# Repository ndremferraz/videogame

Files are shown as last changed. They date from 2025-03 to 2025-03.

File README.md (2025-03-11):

# Video Game Project (Finished🏁)
The purpose of this repository is to document my process of creating a handheld video game console. My intention with this project is to practice some skills realted to embedded software and electronics while I do something fun.

The Project used a Raspberry Pi Pico to connect to control a OLED screen equiped with a SSD1306 chip using I2C protocol, inputs were read from the a Joystick and 4 different buttons.

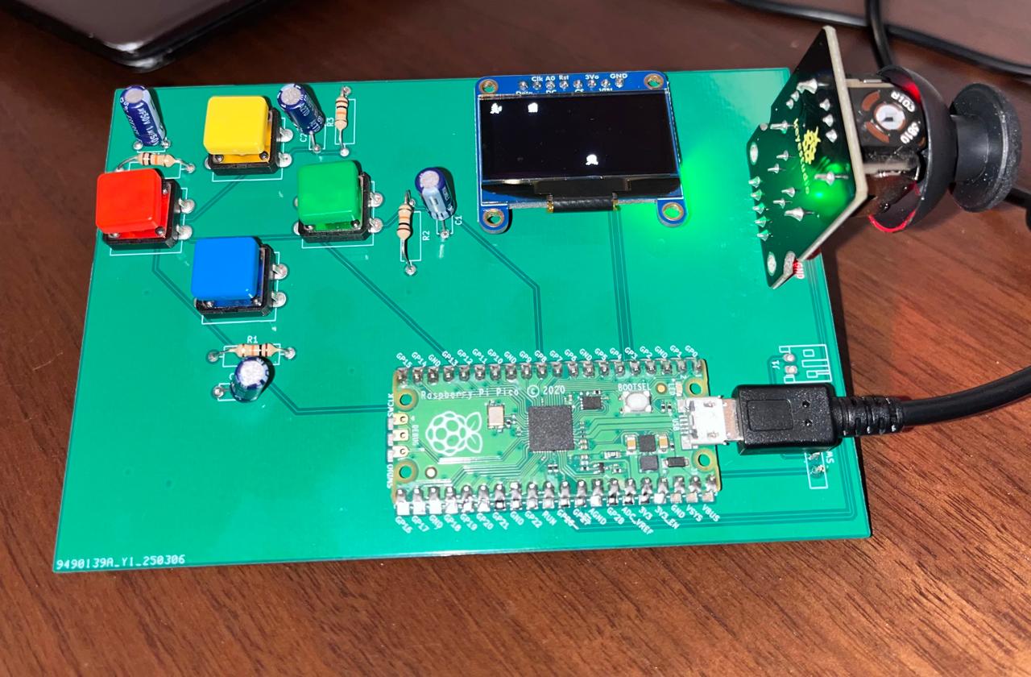
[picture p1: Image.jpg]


In this Project I not only wrote the code using the C/C++ SDK but also designed a PCB for the Circuit. 

The Code can be found under the videogame subfolder and Schematics and PCB found under PacmanProject(Which was the original Idea)

For the creating of the ssd1306.c file I did base myself on the ssd1306 example provided by the raspberry pi foundation, the rest is all mine.

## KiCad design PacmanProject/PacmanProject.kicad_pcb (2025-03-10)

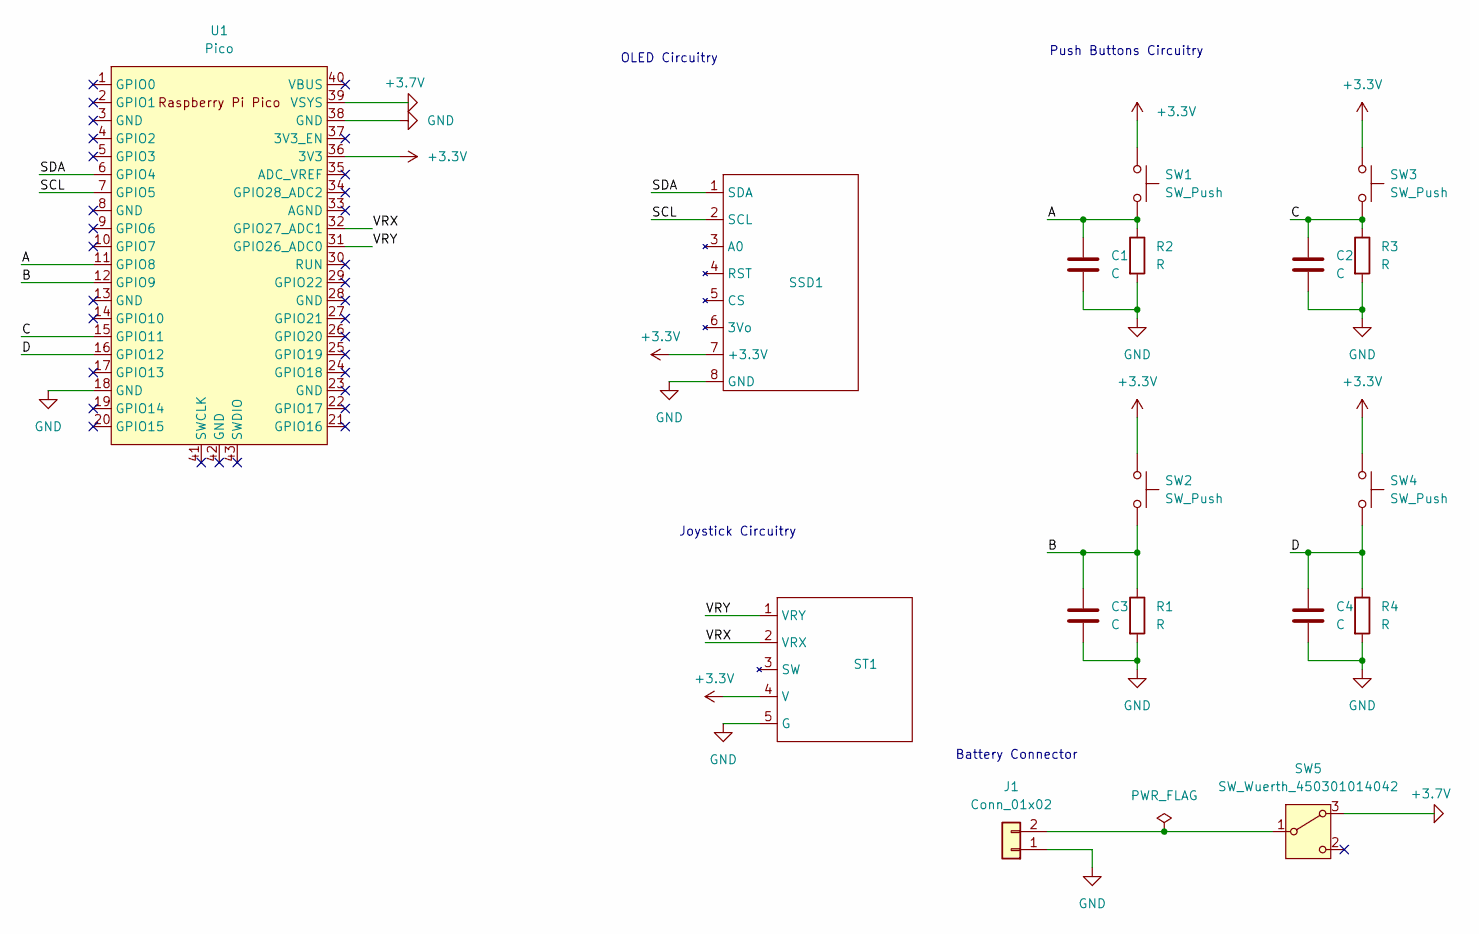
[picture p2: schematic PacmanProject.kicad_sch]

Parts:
C1, C2, C3, C4: C; C_Disc_D4.7mm_W2.5mm_P5.00mm
J1: Conn_01x02; JST_PH_S2B-PH-K_1x02_P2.00mm_Horizontal
R1, R2, R3, R4: R; R_Axial_DIN0309_L9.0mm_D3.2mm_P12.70mm_Horizontal
SSD1: Screen
ST1: joystickV2
SW1, SW2, SW3, SW4: SW_Push; SW_PUSH-12mm_Wuerth-430476085716
SW5: SW_Wuerth_450301014042; SW_Slide-03_Wuerth-WS-SLTV_10x2.5x6.4_P2.54mm
U1: Pico; RPi_Pico_SMD_TH

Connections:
+3.3V: SSD1.7 (+3.3V), ST1.4 (V), SW1.1, SW2.1, SW3.1, SW4.1, U1.36 (3V3)
+3.7V: SW5.3 (A), U1.39 (VSYS)
/A: C1.1, R2.1, SW1.2, U1.11 (GPIO8)
/B: C3.1, R1.1, SW2.2, U1.12 (GPIO9)
/C: C2.1, R3.1, SW3.2, U1.15 (GPIO11)
/D: C4.1, R4.1, SW4.2, U1.16 (GPIO12)
/SCL: SSD1.2 (SCL), U1.7 (GPIO5)
/SDA: SSD1.1 (SDA), U1.6 (GPIO4)
/VRX: ST1.2 (VRX), U1.32 (GPIO27_ADC1)
/VRY: ST1.1 (VRY), U1.31 (GPIO26_ADC0)
GND: C1.2, C2.2, C3.2, C4.2, J1.1, R1.2, R2.2, R3.2, R4.2, SSD1.8 (GND), ST1.5 (G), U1.18 (GND), U1.38 (GND)
unnamed: J1.2, SW5.1 (B)

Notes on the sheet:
Push Buttons Circuitry
Joystick Circuitry
OLED Circuitry
Battery Connector

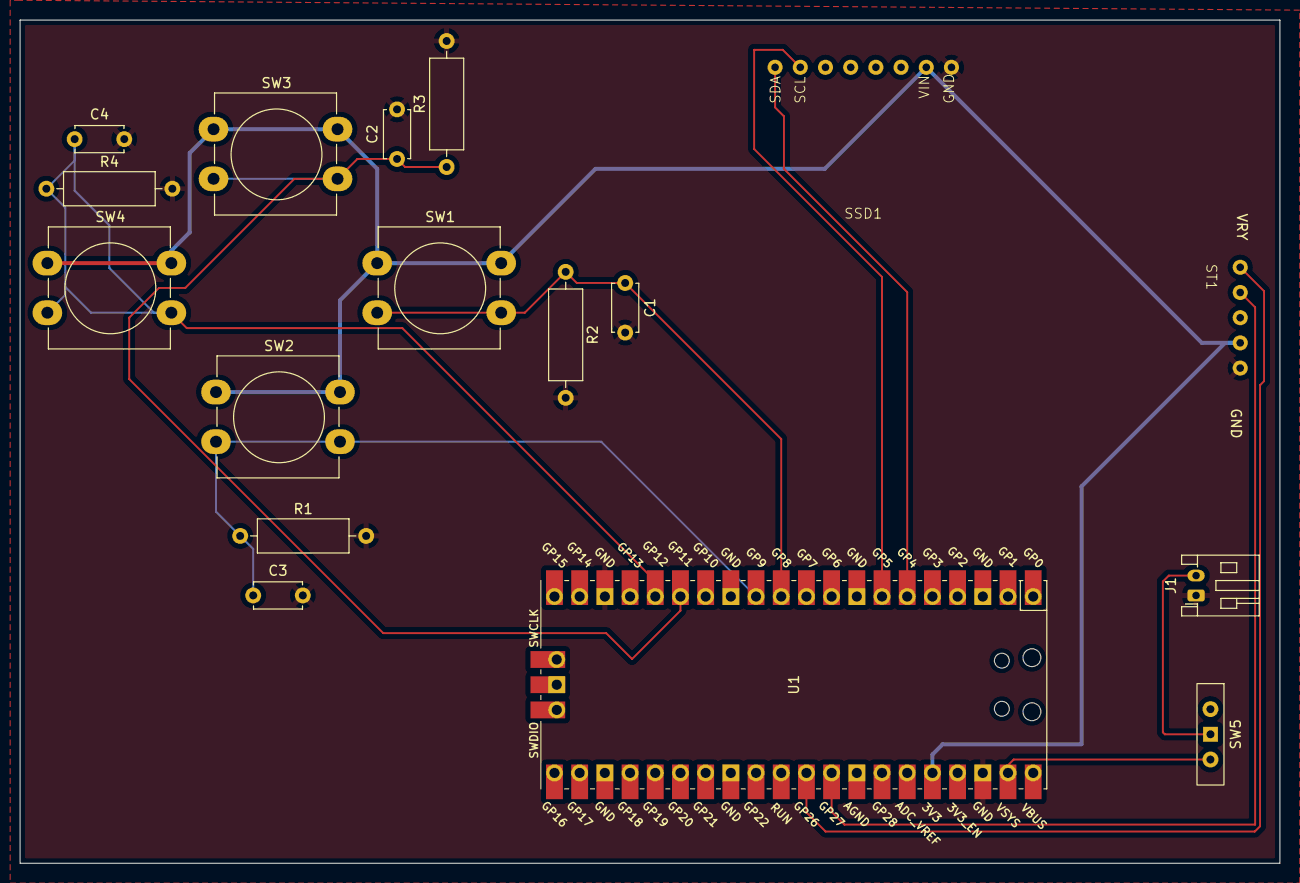
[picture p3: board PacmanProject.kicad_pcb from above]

Board: 2 copper layers, 127.0 x 85.0 mm, 17 parts (0 on the bottom side), 12 nets.

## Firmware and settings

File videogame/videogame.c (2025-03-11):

#include <stdio.h>
#include "pico/rand.h"
#include "pico/stdlib.h"
#include "pico/binary_info.h"
#include "hardware/gpio.h"
#include "hardware/adc.h"
#include "hardware/i2c.h"
#include "ssd1306.h"
#include "character_images.h"
#include "game.h"

//pins 10 and 13 are likely burned :)
//Definitions for the buttons and joystick
#define GREENBUTTON 11
#define YELLOWBUTTON 8
#define REDBUTTON 12
#define BLUEBUTTON 9

#define XJOYSTICK 27
#define YJOYSTICK 26

//Initializing the I/O pins
void init_gpios(){
    gpio_init(GREENBUTTON);
    gpio_init(YELLOWBUTTON);
    gpio_init(REDBUTTON);
    gpio_init(BLUEBUTTON);
    

    gpio_set_dir(GREENBUTTON, GPIO_IN);
    gpio_set_dir(YELLOWBUTTON, GPIO_IN);
    gpio_set_dir(REDBUTTON, GPIO_IN);
    gpio_set_dir(BLUEBUTTON, GPIO_IN);
}

//initializing i2c using the default i2c in the pico
//DATA > GPIO4 
//CLK > GPIO5
void i2c_setup(){

    i2c_init(i2c_default, 100 * 1000);
    gpio_set_function(PICO_DEFAULT_I2C_SDA_PIN, GPIO_FUNC_I2C);
    gpio_set_function(PICO_DEFAULT_I2C_SCL_PIN, GPIO_FUNC_I2C);
    gpio_pull_up(PICO_DEFAULT_I2C_SDA_PIN);
    gpio_pull_up(PICO_DEFAULT_I2C_SCL_PIN);

    bi_decl(bi_2pins_with_func(PICO_DEFAULT_I2C_SDA_PIN, PICO_DEFAULT_I2C_SCL_PIN, GPIO_FUNC_I2C));
}


//function finds the index of bytes of each character 
//each character has a width of 8 bytes stacked vertically 
//we want one byte adjacent down 
//adjacent bytes are to compensate for misallignment   
void bytes_of_characters(struct player *character, uint16_t *byte_list){

    for(uint8_t i = 0; i < 8; i++){
        byte_list[i] = character->x_pos + i + (character->y_pos / 8)* SSD1306_WIDTH; //index of top byte
        byte_list[i+8] = character->x_pos + i + ((character->y_pos / 8) + 1) * SSD1306_WIDTH; //index of bottom byte  
    } 

    /* This sequence of print statements just saved my life
    for(uint8_t i = 0; i < 16; i++){
        if(i==8){
            printf("\n");
        }
        printf("%d ", byte_list[i]);
    }
    printf("\n");
    */
}

//updates the buffer based on character postion given the character image
void update_character_in_buff(struct player *character, uint8_t *buf, uint8_t *img){
    
    //byte_list stores the indexes in the image buffer where the image should go based on character location 
    uint16_t byte_list[16];
    bytes_of_characters(character, byte_list);

    
    for(uint8_t i = 0; i < 8; i++){
        buf[byte_list[i]] |= img[i] << (character->y_pos % 8);
        buf[byte_list[i + 8]] |= img[i] >> (8 - (character->y_pos % 8));            
    }


}


//Updates the screen based on plyaer location 
void render_screen(uint8_t *buf, struct player *p1,
    bool a_pressed, bool c_pressed, 
    struct player *enemy1, struct player *enemy2, struct render_area *frame_area){
    
    //making the buffer all 0s 
    memset(buf, 0, SSD1306_BUF_LEN);

    //updating the player in image buffer
    if(a_pressed){
        update_character_in_buff(p1, buf, player_img_shooting_down);    
    }
    else if(c_pressed){
        update_character_in_buff(p1, buf, player_img_shooting_right);
    }
    else{
        update_character_in_buff(p1, buf, player_img);
    }
    

    //checking if enemies are still alive and updating them in the image buffer 
    if(enemy1->alive){
        update_character_in_buff(enemy1, buf, enemy1_img);
    }
    if(enemy2->alive){
        update_character_in_buff(enemy2, buf, enemy2_img);
    }

    render(buf, frame_area);
}


void restart_game(struct player *p1, struct player *enemy1, struct player *enemy2){
    

    p1->x_pos = 0;
    p1->y_pos = 0;
    enemy1->alive = true;
    enemy2->alive = true; 
    enemy1->x_pos = rand_spawn('x');
    enemy2->x_pos = rand_spawn('x');
    enemy1->y_pos = rand_spawn('y');
    enemy2->y_pos = rand_spawn('y');
    
    SSD1306_send_cmd(SSD1306_SET_INV_DISP);
    sleep_ms(1000);
    SSD1306_send_cmd(SSD1306_SET_NORM_DISP);


}



int main()
{
    stdio_init_all();
    init_gpios();
    i2c_setup();
    adc_init();

    SSD1306_init();

    adc_gpio_init(XJOYSTICK);
    adc_gpio_init(YJOYSTICK);
    adc_set_round_robin(3); //Performing sequential ADC sampling in ADC0 and ADC1

    bool a_pressed, b_pressed, c_pressed, d_pressed = false;
    uint16_t x_read, y_read = 0;

    //spawns player at position 2,2 
    //spawns eneymies at random location 
    struct player p1 = {0,0,true};
    struct player enemy1 = {rand_spawn('x'),rand_spawn('y'),true};
    struct player enemy2 = {rand_spawn('x'),rand_spawn('y'),true};

    struct render_area frame_area = {
        start_col: 0,
        end_col : SSD1306_WIDTH - 1,
        start_page : 0,
        end_page : SSD1306_NUM_PAGES - 1
    };

    calc_render_area_buflen(&frame_area);

    // zero the entire display
    uint8_t buf[SSD1306_BUF_LEN];
    memset(buf, 0, SSD1306_BUF_LEN);
    render(buf, &frame_area);

    while (true) {
        
        a_pressed = gpio_get(GREENBUTTON);
        b_pressed = gpio_get(YELLOWBUTTON);
        c_pressed = gpio_get(REDBUTTON);
        d_pressed = gpio_get(BLUEBUTTON);

        x_read = adc_read();
        y_read = adc_read();


        player_move(x_read, y_read, &p1, d_pressed, b_pressed);
        rand_move(&enemy1);
        rand_move(&enemy2);
        player_shoot(&p1, &enemy1, &enemy2,a_pressed,c_pressed);
        if(!(enemy1.alive) && !(enemy2.alive)){
            restart_game(&p1, &enemy1, &enemy2);
        }
        
        
        //printf("GREEN:%d YELLOW:%d RED:%d BLUE:%d X:%d Y:%d\n", a_pressed, b_pressed, c_pressed, d_pressed, x_read, y_read);
        //printf("Player 1 pos: x = %d y = %d\n", p1.x_pos, p1.y_pos);
        //printf("Enemy 1 pos: x = %d y = %d alive: %d\n", enemy1.x_pos, enemy1.y_pos, enemy1.alive);
        //printf("Enemy 2 pos: x = %d y = %d alive: %d\n", enemy2.x_pos, enemy2.y_pos, enemy2.alive);

        render_screen(buf, &p1, a_pressed, c_pressed, &enemy1, &enemy2, &frame_area);
    

        sleep_ms(150);

    }
}

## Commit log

2025-01-28 Buttons implemented
2025-01-31 i2c detection implemented
2025-01-31 i2c address found
2025-02-12 fixed the characters for vertical byte scheme and display them statically
    [videogame.c]
2025-02-12 Characters can now be display and move in the display but the movement scheme is wrong
    [videogame.c]
2025-02-13 Fixed the uint8_t overflow issue now game is fully functional
    [videogame.c]
2025-02-13 delay increased to avoid crashing
    [videogame.c]
2025-02-24 adding KiCAD files
    [PacmanProject.kicad_pcb, PacmanProject.kicad_sch, batteryConnector.kicad_sch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]
2025-03-10 Fixed the Connections to display on PCB
    [1306_i2c.fzz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]
